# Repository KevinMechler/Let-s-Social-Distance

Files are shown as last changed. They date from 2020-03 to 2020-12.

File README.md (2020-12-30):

# Let's Social Distance

A derivative of the "Let's Split" 40% split ortholinear keyboard originally made by [u/wootpatoot](https://www.reddit.com/user/wootpatoot/).

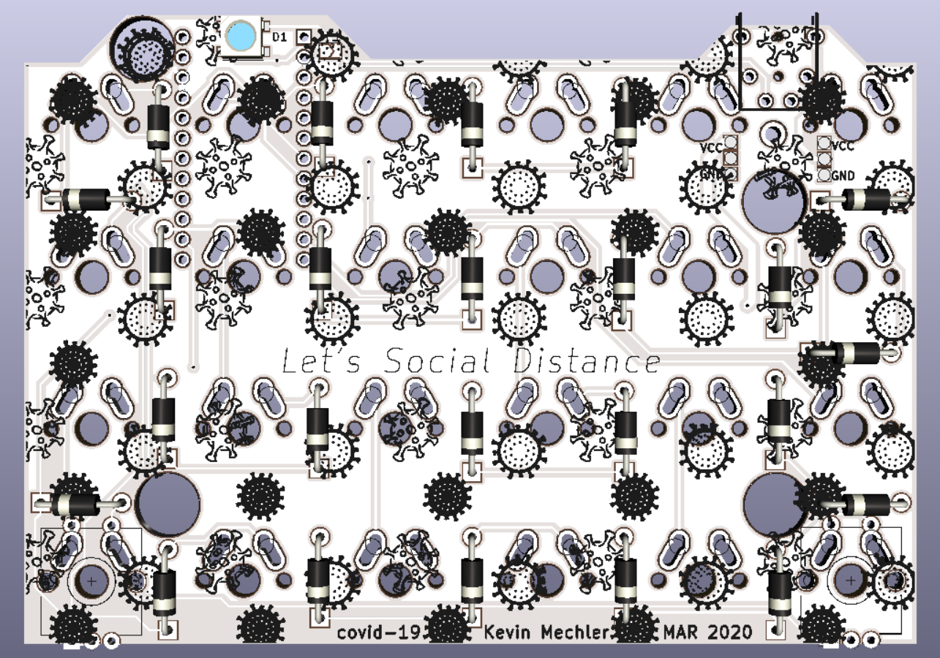
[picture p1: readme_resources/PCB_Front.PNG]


This was re-designed during my spring break that was extended by the COVID-19 pandemic.
The PCB silkscreen design features artisitic depictions of the coronavirus itself.

New Features:
* Support for a single encoder per PCB in the bottom left or right corner.

    * Optional switch in encoder will be part of the key switch matrix.

* Status LED above the Pro-Micro on each half, controlled by the primary Pro-Micro.

    * Data is carried over TRRS cable

* Minimal silkscreen text 

    * See the layout file for diode locations
    * The stripe of the diode goes towards the square pad.
    
* Removed I2C communication lines

    * To allow for LED data lines to be carried by the TRRS cable

How to Assemble:
* [Let's Split Build Guide](https://github.com/nicinabox/lets-split-guide)

How to Use the Encoders:
* When constructing my keyboard, I decided not to include an encoder.
* Users interested in enabling the encoder should seek examples using the QMK firmware packages.
* The encoder pushbutton pins are connected to imitate a keyboard switch
* EncA is pin 2 and EncB is pin 4 on the Pro Micro.

How to Use the LEDs:
* I decided not to populate the LEDs, though this was designed to accomodate one WS2812B (NeoPixel) RGB LED on either side of each half.
* Since WS2812B LEDs pass-through, a jumper footprint is required to bypass the LEDs on one side and use the others.

Suggestions for future versions:
* Place GND on the TRRS "sleeve" and VCC on the TRRS "tip" to remove potential shorts when a TRS cable is used. This may also require adding a normally-open jumper for the LED data pin on the TRRS connector to allow it to float with the main signal line in the case of a TRS cable.
* Review and improve the LED placement and routing.

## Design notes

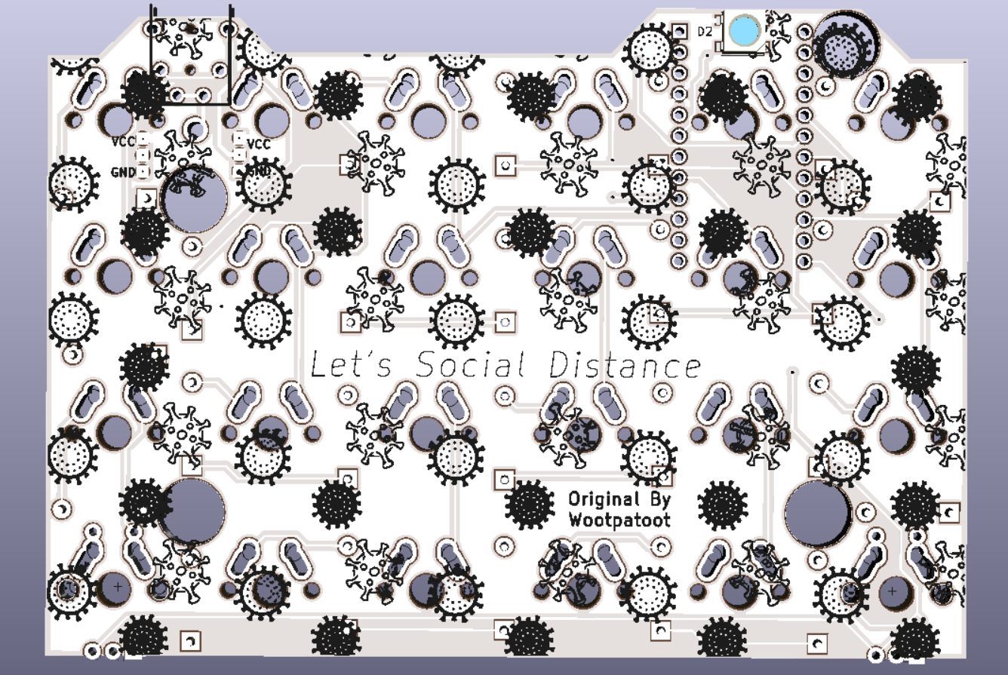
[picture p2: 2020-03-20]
readme_resources/PCB_Back.PNG

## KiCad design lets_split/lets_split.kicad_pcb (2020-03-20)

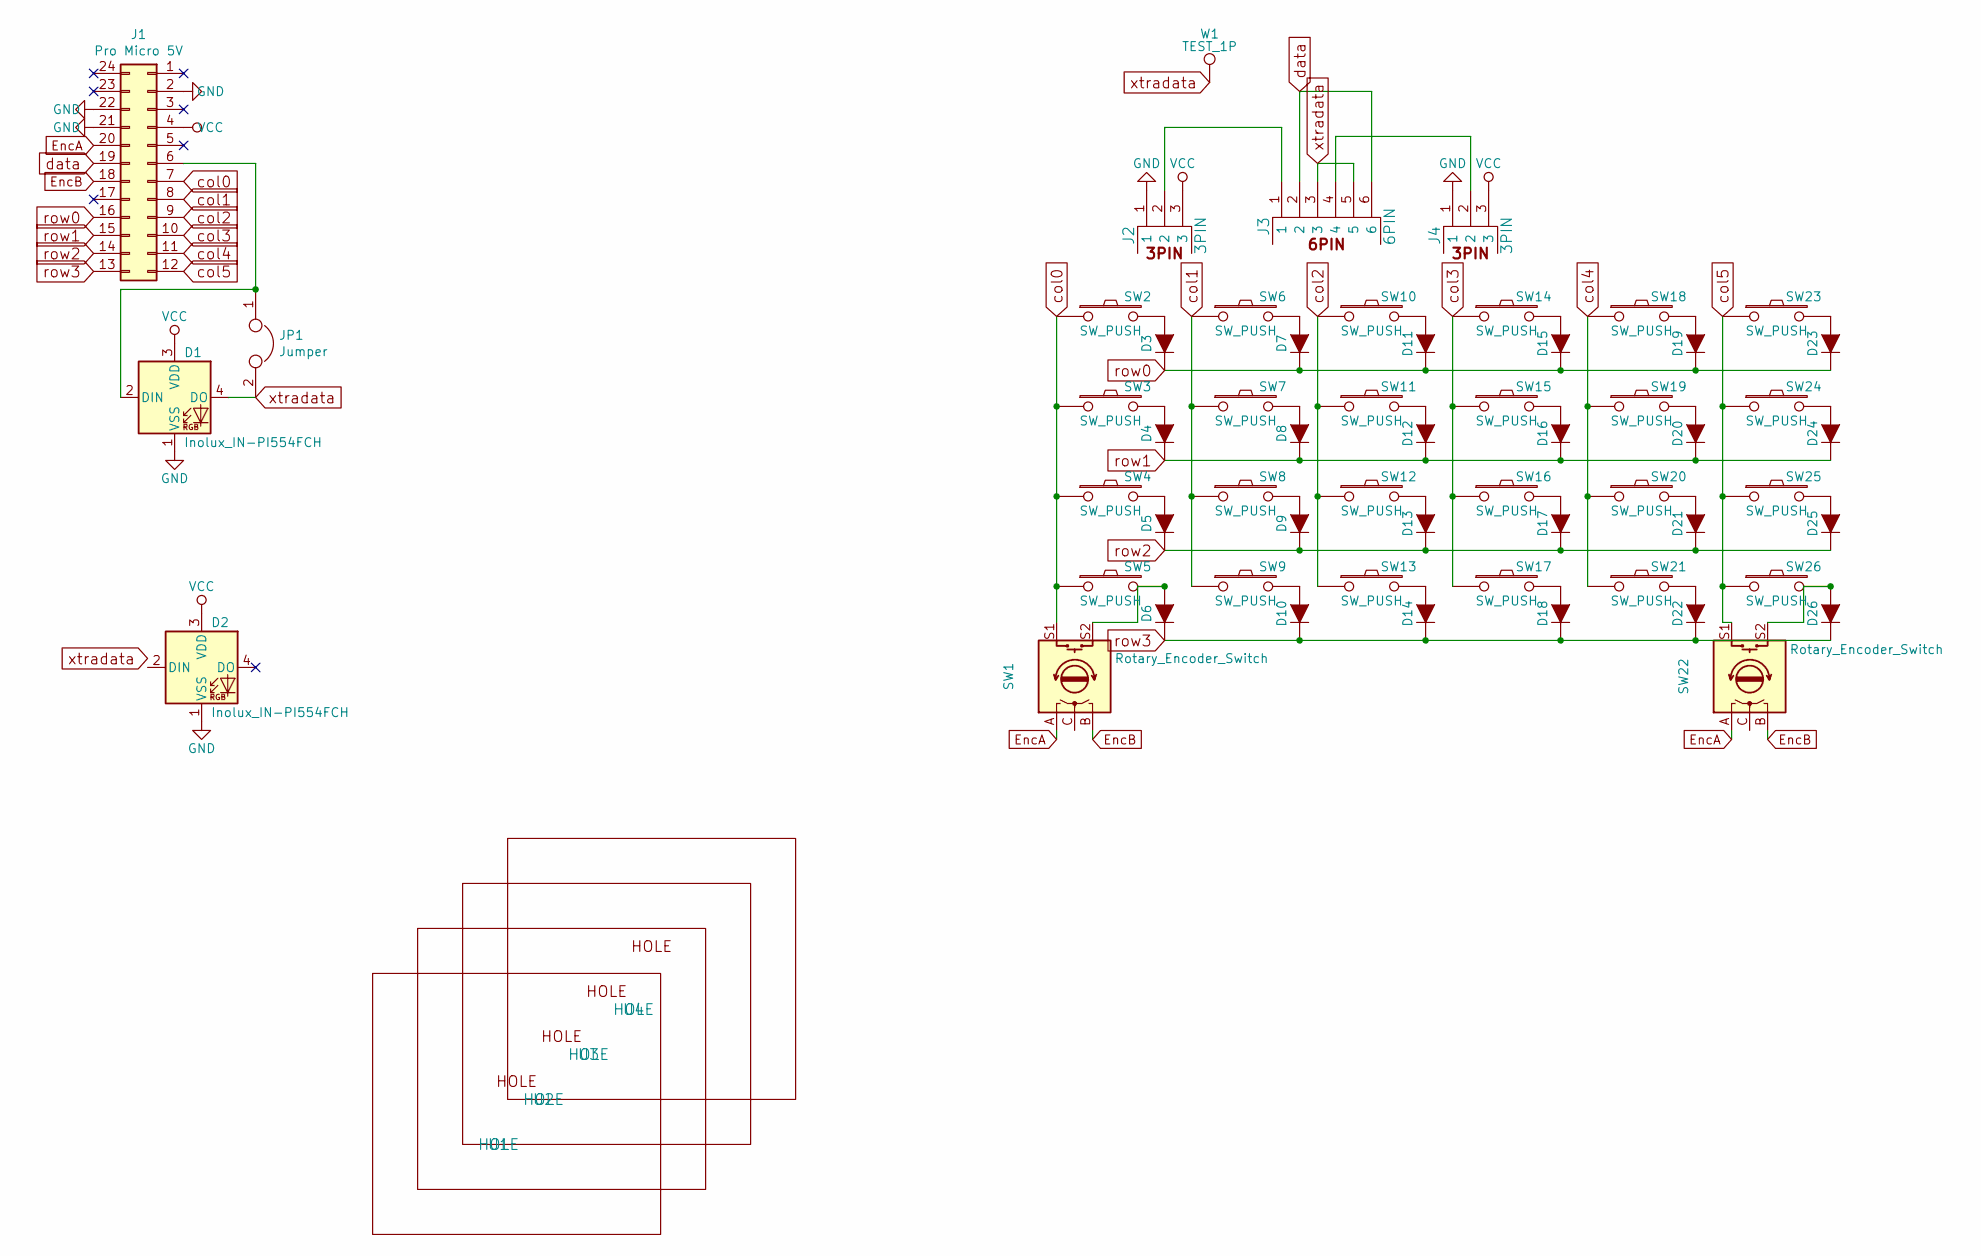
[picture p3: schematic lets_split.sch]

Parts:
D1, D2: Inolux_IN-PI554FCH; LED_Inolux_IN-PI554FCH_PLCC4_5.0x5.0mm_P3.2mm; Part Number IN-PI554FCH
D3, D4, D5, D6, D7, D8, D9, D10, D11, D12, D13, D14, D15, D16, D17, D18, D19, D20, D21, D22, D23, D24, D25, D26: D; D_DO-41_SOD81_P10.16mm_Horizontal
J1: Pro Micro 5V; Pro_Micro
J2, J4: 3PIN; 3_pin_TP
J3: 6PIN; 4pin35mmAudio
JP1: Jumper; SolderJumper-2_P1.3mm_Open_TrianglePad1.0x1.5mm
SW1, SW22: Rotary_Encoder_Switch; RotaryEncoder_Alps_EC12E-Switch_Vertical_H20mm
SW2, SW3, SW4, SW5, SW6, SW7, SW8, SW9, SW10, SW11, SW12, SW13, SW14, SW15, SW16, SW17, SW18, SW19, SW20, SW21, SW23, SW24, SW25, SW26: SW_PUSH; MXALPS_FLIP
U1, U2, U3, U4: HOLE; LS_HOLE
W1: TEST_1P; TestPoint_Plated_Hole_D2.0mm

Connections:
EncA: J1.20, SW1.A, SW22.A
EncB: J1.18, SW1.B, SW22.B
GND: D1.1 (VSS), D2.1 (VSS), J1.2, J1.21, J1.22, J2.1, J4.1
unnamed: D1.2 (DIN), J1.6, JP1.1
unnamed: D3.2 (A), SW2.2
unnamed: D4.2 (A), SW3.2
unnamed: D5.2 (A), SW4.2
unnamed: D6.2 (A), SW1.S2, SW5.2
unnamed: D7.2 (A), SW6.2
unnamed: D8.2 (A), SW7.2
unnamed: D9.2 (A), SW8.2
unnamed: D10.2 (A), SW9.2
unnamed: D11.2 (A), SW10.2
unnamed: D12.2 (A), SW11.2
unnamed: D13.2 (A), SW12.2
unnamed: D14.2 (A), SW13.2
unnamed: D15.2 (A), SW14.2
unnamed: D16.2 (A), SW15.2
unnamed: D17.2 (A), SW16.2
unnamed: D18.2 (A), SW17.2
unnamed: D19.2 (A), SW18.2
unnamed: D20.2 (A), SW19.2
unnamed: D21.2 (A), SW20.2
unnamed: D22.2 (A), SW21.2
unnamed: D23.2 (A), SW23.2
unnamed: D24.2 (A), SW24.2
unnamed: D25.2 (A), SW25.2
unnamed: D26.2 (A), SW22.S2, SW26.2
unnamed: J2.2, J3.1
unnamed: J3.4, J4.2
VCC: D1.3 (VDD), D2.3 (VDD), J1.4, J2.3, J4.3
col0: J1.7, SW1.S1, SW2.1, SW3.1, SW4.1, SW5.1
col1: J1.8, SW6.1, SW7.1, SW8.1, SW9.1
col2: J1.9, SW10.1, SW11.1, SW12.1, SW13.1
col3: J1.10, SW14.1, SW15.1, SW16.1, SW17.1
col4: J1.11, SW18.1, SW19.1, SW20.1, SW21.1
col5: J1.12, SW22.S1, SW23.1, SW24.1, SW25.1, SW26.1
data: J1.19, J3.2, J3.6
row0: D3.1 (K), D7.1 (K), D11.1 (K), D15.1 (K), D19.1 (K), D23.1 (K), J1.16
row1: D4.1 (K), D8.1 (K), D12.1 (K), D16.1 (K), D20.1 (K), D24.1 (K), J1.15
row2: D5.1 (K), D9.1 (K), D13.1 (K), D17.1 (K), D21.1 (K), D25.1 (K), J1.14
row3: D6.1 (K), D10.1 (K), D14.1 (K), D18.1 (K), D22.1 (K), D26.1 (K), J1.13
xtradata: D1.4 (DO), J3.3, J3.5, JP1.2, W1.1

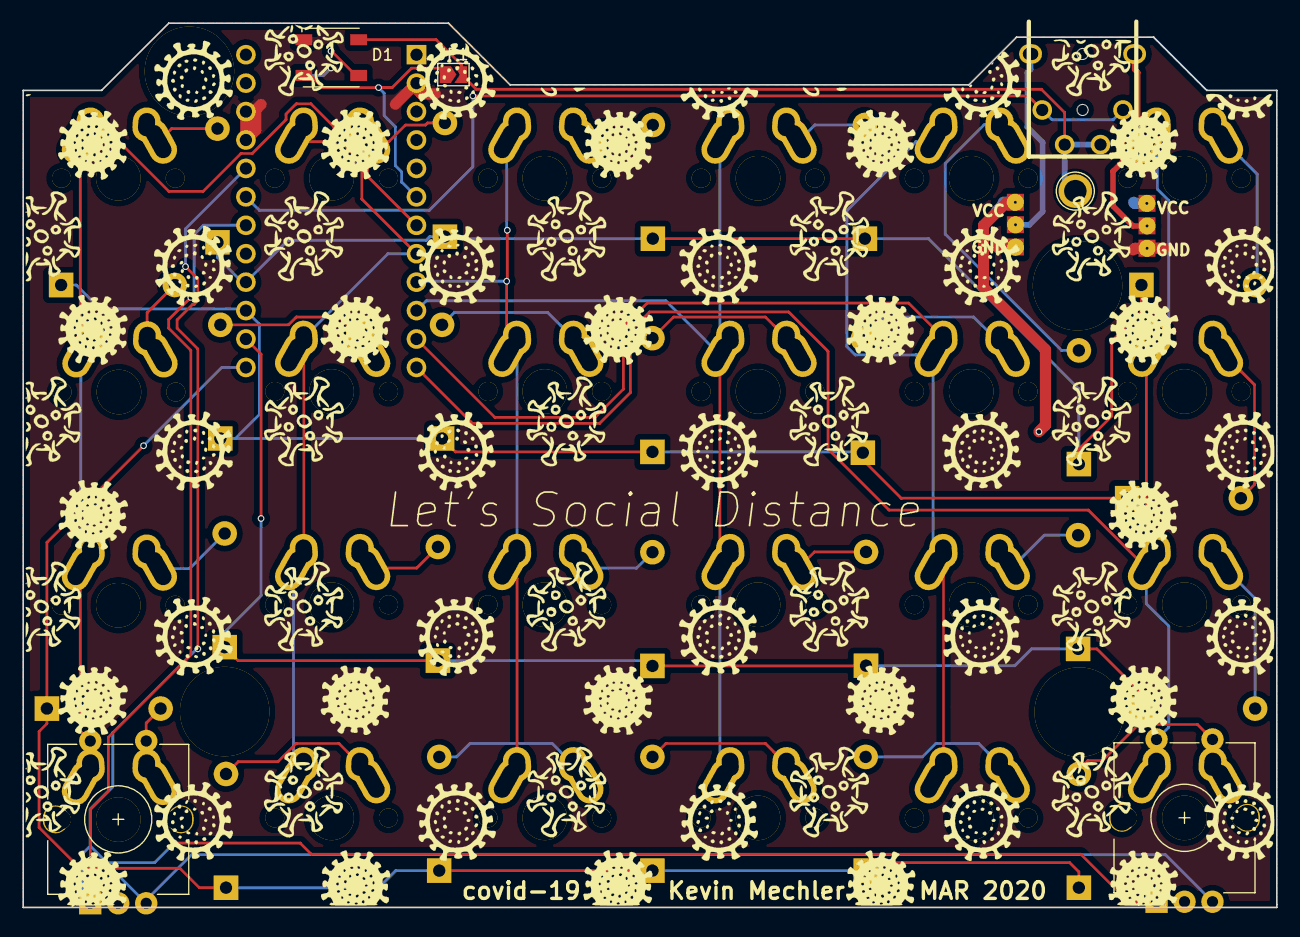
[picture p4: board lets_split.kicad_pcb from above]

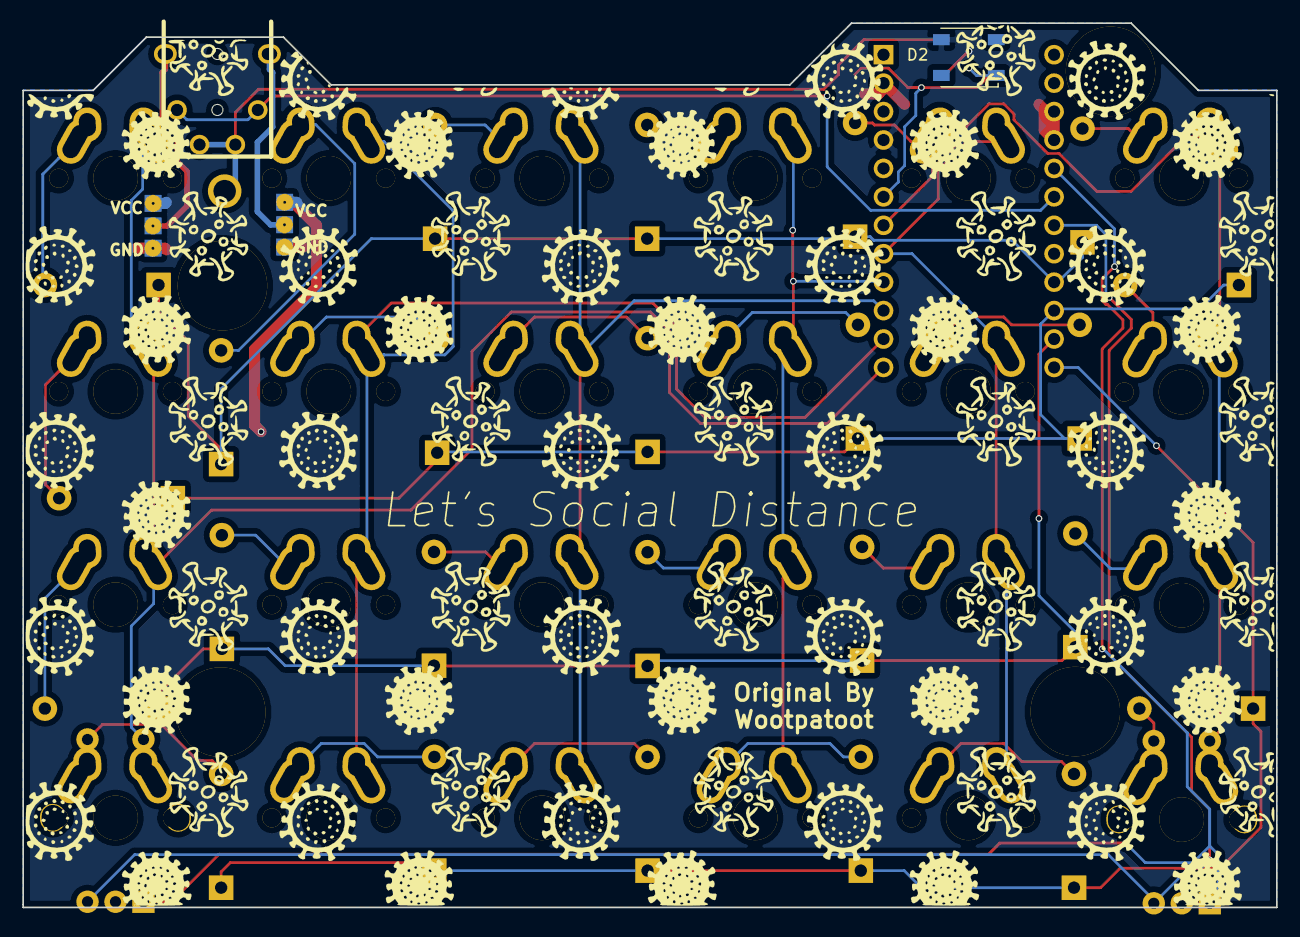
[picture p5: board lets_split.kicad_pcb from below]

Board: 2 copper layers, 112.0 x 79.0 mm, 62 parts (2 on the bottom side), 43 nets.

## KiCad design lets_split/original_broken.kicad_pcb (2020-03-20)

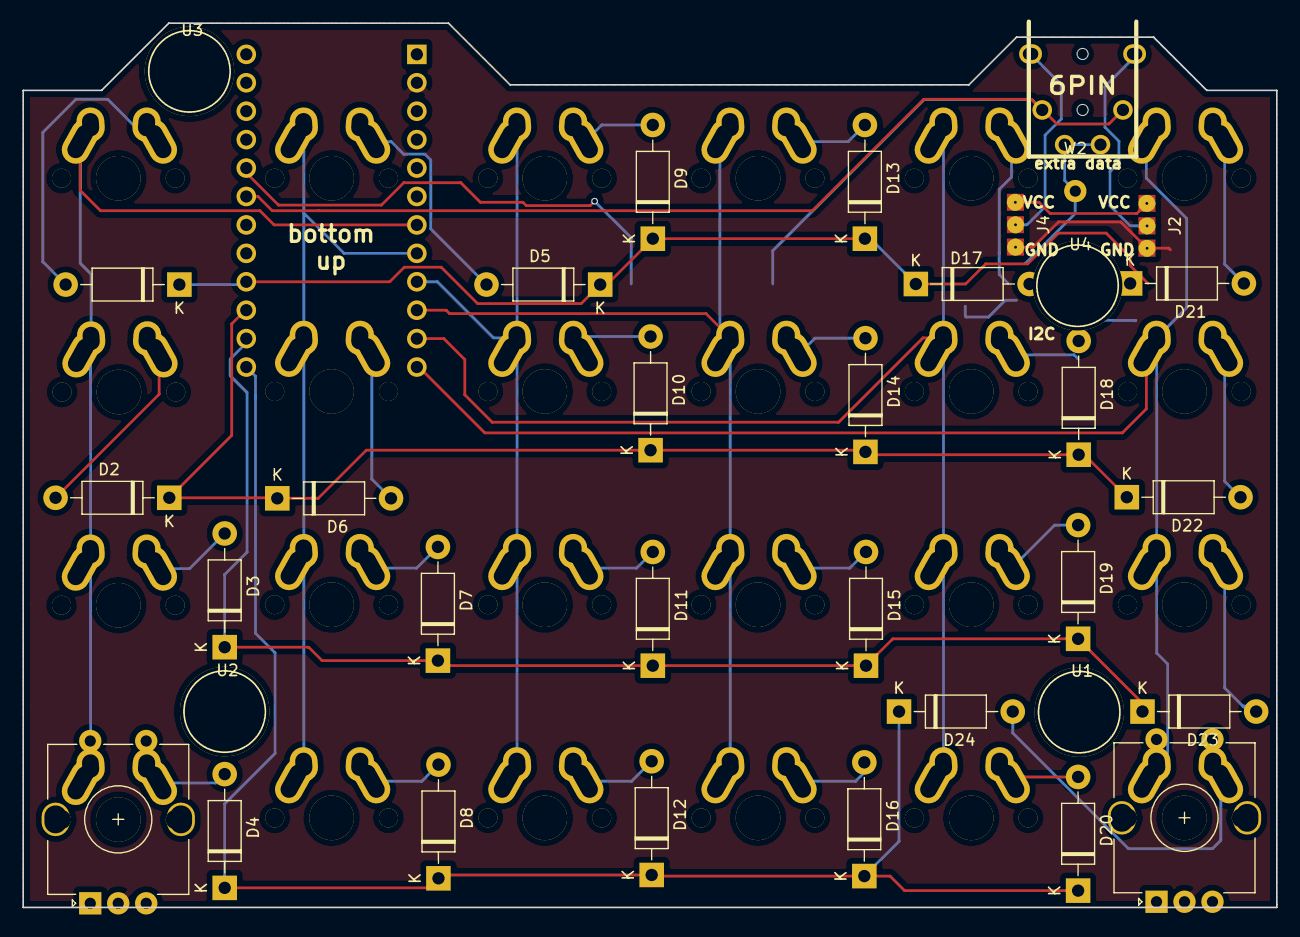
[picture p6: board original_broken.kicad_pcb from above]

Board: 2 copper layers, 112.0 x 79.0 mm, 59 parts (1 on the bottom side), 42 nets.

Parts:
D1, D2, D3, D4, D5, D6, D7, D8, D9, D10, D11, D12, D13, D14, D15, D16, D17, D18, D19, D20, D21, D22, D23, D24: D; D_DO-41_SOD81_P10.16mm_Horizontal
J2, J4: 3PIN; jumper
J3: 6PIN; 4pin35mmAudio
SW1, SW22: Rotary_Encoder_Switch; RotaryEncoder_Alps_EC12E-Switch_Vertical_H20mm
SW2, SW3, SW4, SW5, SW6, SW7, SW8, SW9, SW10, SW11, SW12, SW13, SW14, SW15, SW16, SW17, SW18, SW19, SW20, SW21, SW23, SW24, SW25, SW26: SW_PUSH; MXALPS_FLIP
U1: TEENSY_2.0
U1#2, U2, U3, U4: HOLE
W2: TEST_1P; SolderWirePad_single_2mmDrill

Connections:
EncA: SW1.A, SW22.A
EncB: SW1.B, SW22.B
GND: J2.1, J4.1, SW1.C, SW22.C, U1.2
unnamed: D1.2, SW2.2
unnamed: D2.2, SW3.2
unnamed: D3.2, SW4.2
unnamed: D4.2, SW1.S2, SW5.2
unnamed: D5.2, SW6.2
unnamed: D6.2, SW7.2
unnamed: D7.2, SW8.2
unnamed: D8.2, SW9.2
unnamed: D9.2, SW10.2
unnamed: D10.2, SW11.2
unnamed: D11.2, SW12.2
unnamed: D12.2, SW13.2
unnamed: D13.2, SW14.2
unnamed: D14.2, SW15.2
unnamed: D15.2, SW16.2
unnamed: D16.2, SW17.2
unnamed: D17.2, SW18.2
unnamed: D18.2, SW19.2
unnamed: D19.2, SW20.2
unnamed: D20.2, SW21.2
unnamed: D21.2, SW23.2
unnamed: D22.2, SW24.2
unnamed: D23.2, SW25.2
unnamed: D24.2, SW22.S2, SW26.2
unnamed: J2.2, J3.1
unnamed: J3.4, J4.2
VCC: J2.3, J4.3, U1.4
col0: SW1.S1, SW2.1, SW3.1, SW4.1, SW5.1, U1.7
col1: SW6.1, SW7.1, SW8.1, SW9.1, U1.8
col2: SW10.1, SW11.1, SW12.1, SW13.1, U1.9
col3: SW14.1, SW15.1, SW16.1, SW17.1, U1.10
col4: SW18.1, SW19.1, SW20.1, SW21.1, U1.11
col5: SW22.S1, SW23.1, SW24.1, SW25.1, SW26.1, U1.12
data: J3.2, J3.6, U1.24
row0: D1.1, D5.1, D9.1, D13.1, D17.1, D21.1, U1.21
row1: D2.1, D6.1, D10.1, D14.1, D18.1, D22.1, U1.20
row2: D3.1, D7.1, D11.1, D15.1, D19.1, D23.1, U1.19
row3: D4.1, D8.1, D12.1, D16.1, D20.1, D24.1, U1.18
xtradata: J3.3, J3.5, W2.1
